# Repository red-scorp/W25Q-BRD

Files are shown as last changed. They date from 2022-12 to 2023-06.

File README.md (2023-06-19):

# W25Q-BRD project

W25Q-BRD project is meant to provide people with cheap SPI flash breakout board.

## W25Q-BRD

**W25Q-BRD** is a breakout board for DIY use.
This board features 128Mbit (16MB) serial flash chip W25Q128JVSIQ and M3 mounting hole.
The flash board runs on 3.3V and supports SPI and QSPI transfer modes.

Preview:

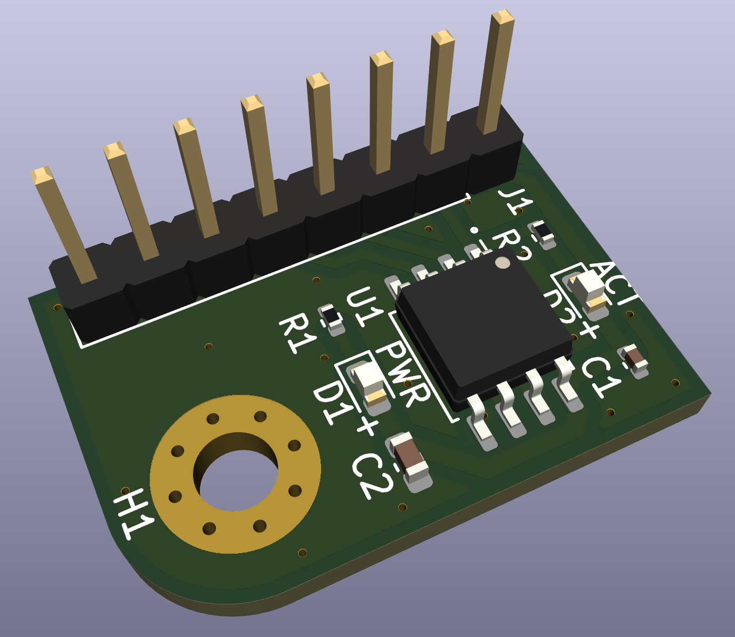
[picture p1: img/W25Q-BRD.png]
W25Q-BRD preview


[Schematics in PDF format](doc/W25Q-BRD.pdf)

Features:

- Uses 3.3V voltage
- Runs in SPI and QSPI modes
- Simple 2 layer board design
- Common for DIY 2.54mm pitch connector
- Features SIOC-8 and WSON-8(6x5) footprints

CAM files are available.
JLCPCB BOM and CPL files are available.

### W25Q-BRD v1.0

Preview:

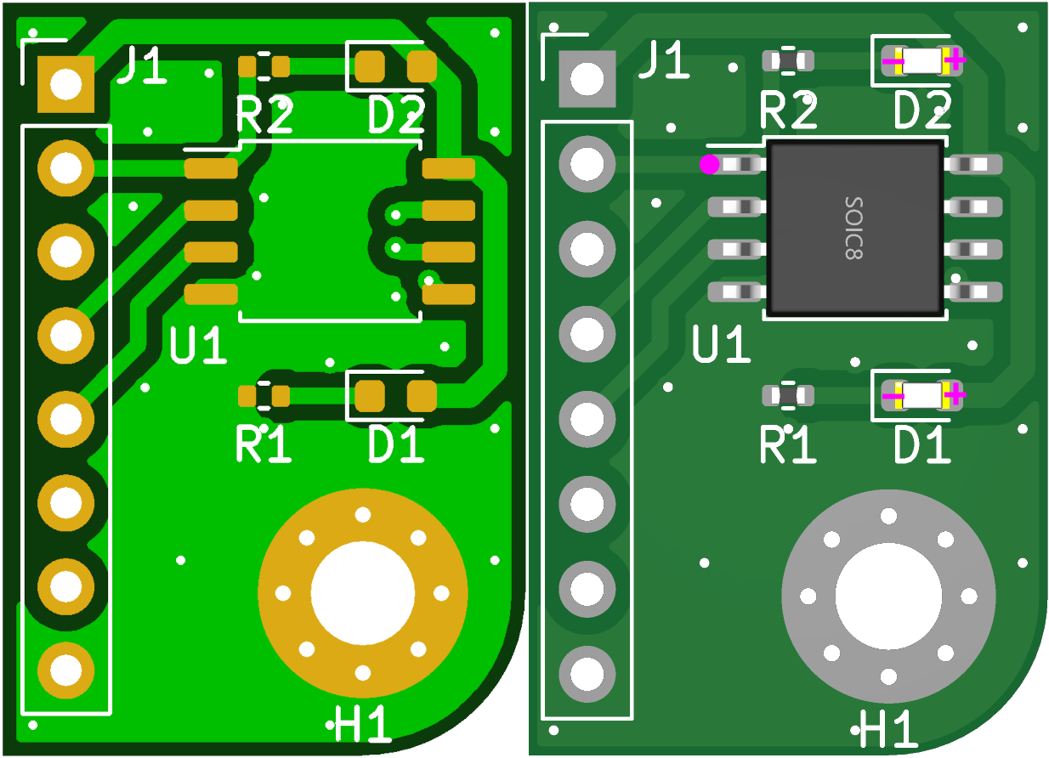
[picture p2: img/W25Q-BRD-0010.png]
W25Q-BRD v1.0 preview


Initial version of the board.

### W25Q-BRD v1.1

Preview:

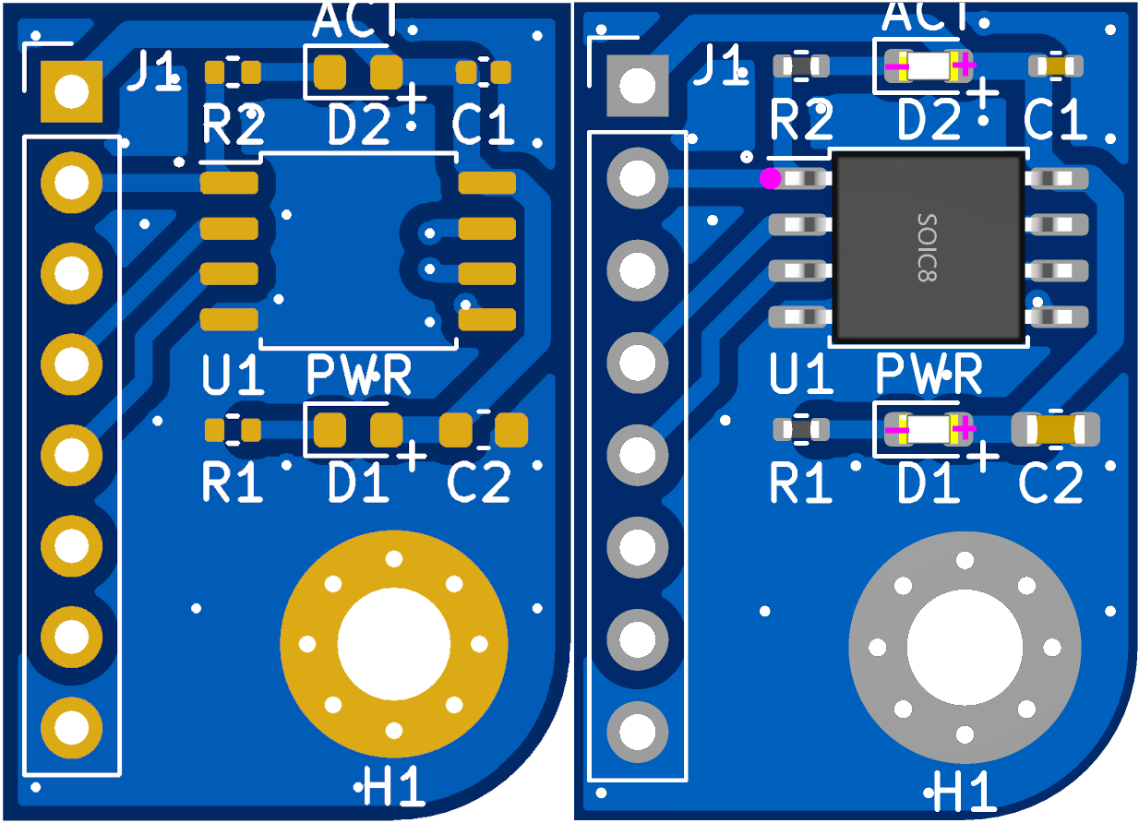
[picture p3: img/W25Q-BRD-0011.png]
W25Q-BRD v1.1 preview


Added capacitors for better voltage stability.

### W25Q-BRD v1.2

Preview:

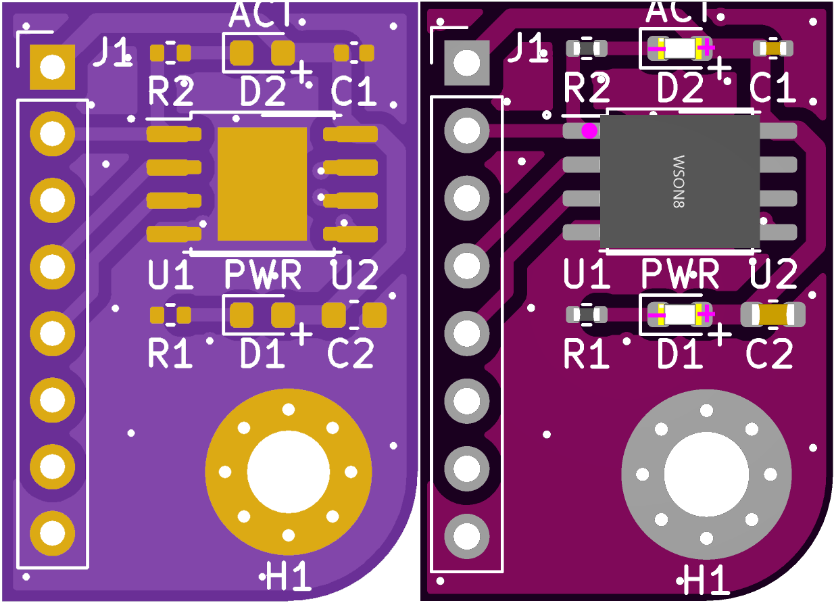
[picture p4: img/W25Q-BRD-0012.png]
W25Q-BRD v1.2 preview


Added alternative WSON footprint to add more fabrication options.

## Board pinout

<table>
    <thead>
        <tr>
            <th>Pin</th><th>SPI mode</th><th>QSPI mode</th>
        </tr>
    </thead>
    <tbody>
        <tr>
            <td>3V3</td><td colspan=2>VCC of the chip, 3.3V</td>
        </tr>
        <tr>
            <td>NCS</td><td colspan=2>Chip select signal</td>
        </tr>
        <tr>
            <td>IO0</td><td>Data input</td><td>Data IO 0</td>
        </tr>
        <tr>
            <td>IO1</td><td>Data output</td><td>Data IO 1</td>
        </tr>
        <tr>
            <td>IO2</td><td>-</td><td>Data IO 2</td>
        </tr>
        <tr>
            <td>IO3</td><td>-</td><td>Data IO 3</td>
        </tr>
        <tr>
            <td>CLK</td><td colspan=2>(Q)SPI clock signal</td>
        </tr>
        <tr>
            <td>GND</td><td colspan=2>Ground</td>
        </tr>
    </tbody>
</table>

## Links

- Flash chip [W25Q128JVSIQ datasheet](doc/1811142111_Winbond-Elec-W25Q128JVSIQ_C97521.pdf)

## How to help

Your contributions as code, resources, or finances are welcome! Please contact me directly via email at andriy.golovnya@gmail.com or through my [GitHub profile](https://github.com/red-scorp).

If you'd like to make a financial contribution, you can donate via [PayPal](http://paypal.me/redscorp) or [Ko-Fi](http://ko-fi.com/redscorp). Your support is greatly appreciated.

Thanks in advance!

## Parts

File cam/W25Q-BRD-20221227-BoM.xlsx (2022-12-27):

Designator | Footprint | Comment | LCSC Part #
R1 | 0402 | 5k1 | C25905
R2 | 0402 | 10k | C25744
U1 | SOIC-8_208mil | W25Q128JVSIQ | C97521
D1 | 0603 | GREEN | C72043
D2 | 0603 | RED | C2286
C1 | 0402 | 100nF | C1525
C2 | 0603 | 1uF | C15849
U2 | WSON-8-EP(6x5) | W25Q128JVPIQ | C190862

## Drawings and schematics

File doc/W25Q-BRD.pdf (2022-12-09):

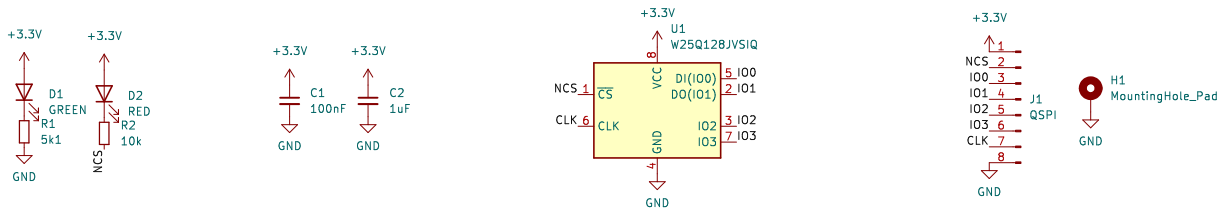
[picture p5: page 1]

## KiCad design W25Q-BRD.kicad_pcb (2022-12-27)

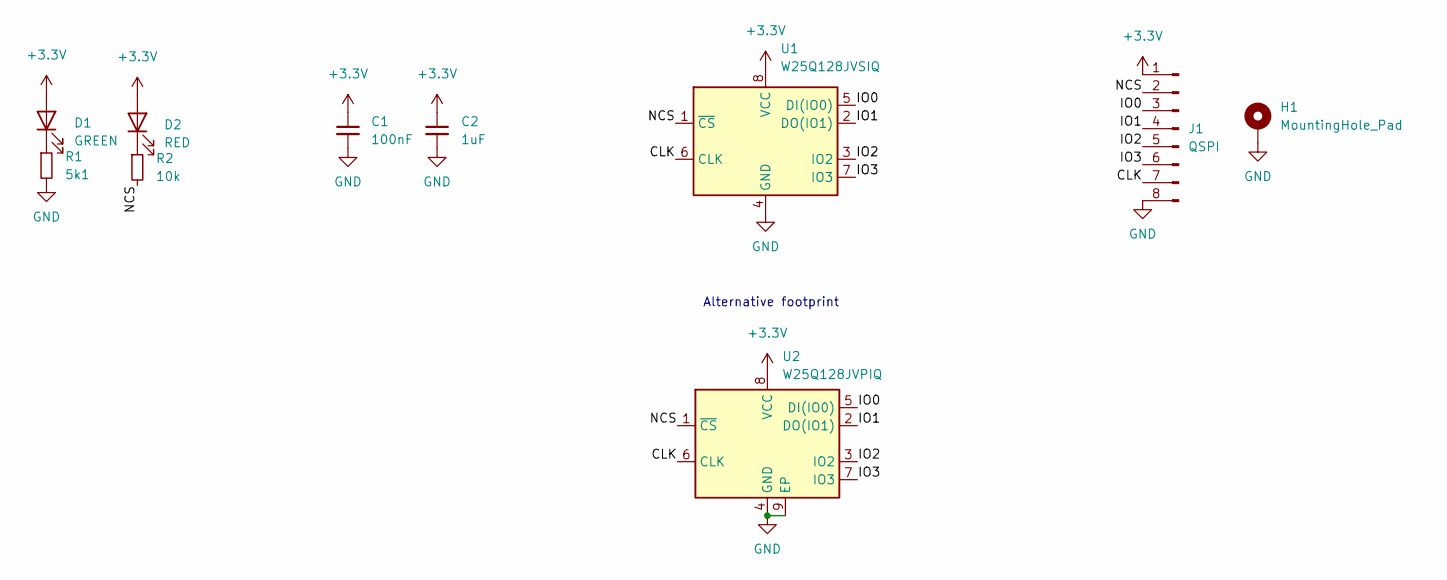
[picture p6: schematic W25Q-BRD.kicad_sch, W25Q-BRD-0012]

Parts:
C1: 100nF; C_0402_1005Metric
C2: 1uF; C_0603_1608Metric
D1: GREEN; LED_0603_1608Metric
D2: RED; LED_0603_1608Metric
H1: MountingHole_Pad; MountingHole_3.2mm_M3_Pad_Via
J1: QSPI; PinHeader_1x08_P2.54mm_Vertical
R1: 5k1; R_0402_1005Metric
R2: 10k; R_0402_1005Metric
U1: W25Q128JVSIQ; SOIC-8_5.23x5.23mm_P1.27mm
U2: W25Q128JVPIQ; WSON-8-1EP_6x5mm_P1.27mm_EP3.4x4.3mm

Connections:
+3.3V: C1.1, C2.1, D1.2 (A), D2.2 (A), J1.1, U1.8 (VCC), U2.8 (VCC)
/CLK: J1.7, U1.6 (CLK), U2.6 (CLK)
/IO0: J1.3, U1.5 (DI(IO0)), U2.5 (DI(IO0))
/IO1: J1.4, U1.2 (DO(IO1)), U2.2 (DO(IO1))
/IO2: J1.5, U1.3 (IO2), U2.3 (IO2)
/IO3: J1.6, U1.7 (IO3), U2.7 (IO3)
/NCS: J1.2, R2.2, U1.1 (~CS), U2.1 (~CS)
GND: C1.2, C2.2, H1.1, J1.8, R1.2, U1.4 (GND), U2.4 (GND), U2.9 (EP)
unnamed: D1.1 (K), R1.1
unnamed: D2.1 (K), R2.1

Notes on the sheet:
Alternative footprint

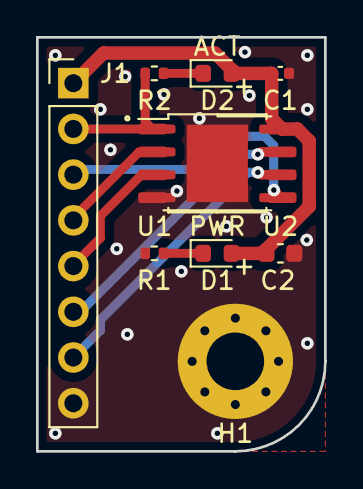
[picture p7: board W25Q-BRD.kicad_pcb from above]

Board: 2 copper layers, 16.0 x 23.0 mm, 10 parts (0 on the bottom side), 10 nets.

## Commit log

2022-12-04 New board project created.
    [W25Q-BRD.kicad_pcb, W25Q-BRD.kicad_sch]
2022-12-04 Finished board design.
    [W25Q-BRD.kicad_pcb, W25Q-BRD.kicad_sch]
2022-12-04 Added CAM files
    [W25Q-BRD.kicad_pcb]
2022-12-04 Moved some components around. Generated CAM files.
    [W25Q-BRD.kicad_pcb]
2022-12-04 Generated BoM and CPL files.
    [W25Q-BRD-20221204-BoM.xlsx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]
2022-12-04 Fixed BoM and CPL files during ordering.
    [W25Q-BRD-20221204-BoM.xlsx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]
2022-12-05 Version 1.1. Added 2 caps. Added few texts.
    [W25Q-BRD.kicad_pcb, W25Q-BRD.kicad_sch]
2022-12-05 Generated CAM, BoM and CPL files.
    [W25Q-BRD-20221204-BoM.xlsx, W25Q-BRD-20221205-BoM.xlsx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]
2022-12-09 Added fitting 3D mode for the flash chip.
    [W25Q-BRD.kicad_pcb]
2022-12-09 Generated PDF schematics.
2022-12-27 Added alternative footprint for WSOT-8 version of the chip.
    [W25Q-BRD.kicad_pcb, W25Q-BRD.kicad_sch]
2022-12-31 Added side-by-side images for board previews.
